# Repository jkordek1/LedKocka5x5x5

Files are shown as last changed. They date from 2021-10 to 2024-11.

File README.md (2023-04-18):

# LedKocka5x5x5


[]()



## What is it?
Just another 125 LED cube powered by ATmega16 microcontroller and HC595 shift registers.

## Video
Video of it in action: https://www.youtube.com/watch?v=YpSFf-s8Nvs

## Problems
Project BOM is not optimal. Due to electronic components shortage, "on-hand" available components were used.

## Images
 LED_Cube_5x5x5
<p align="center">
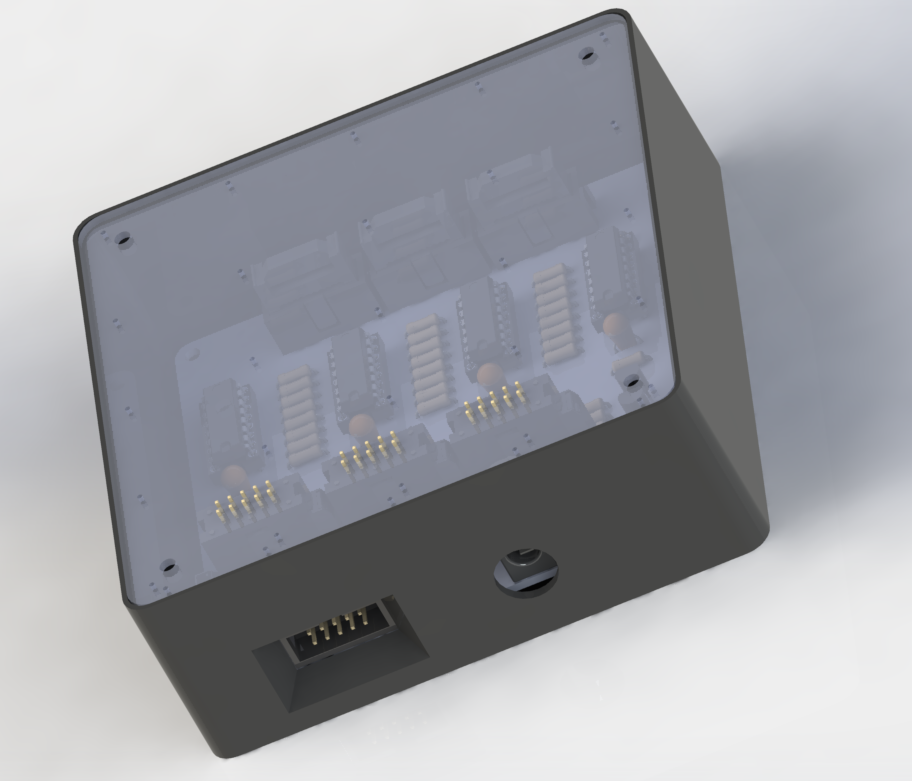
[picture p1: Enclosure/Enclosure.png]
 
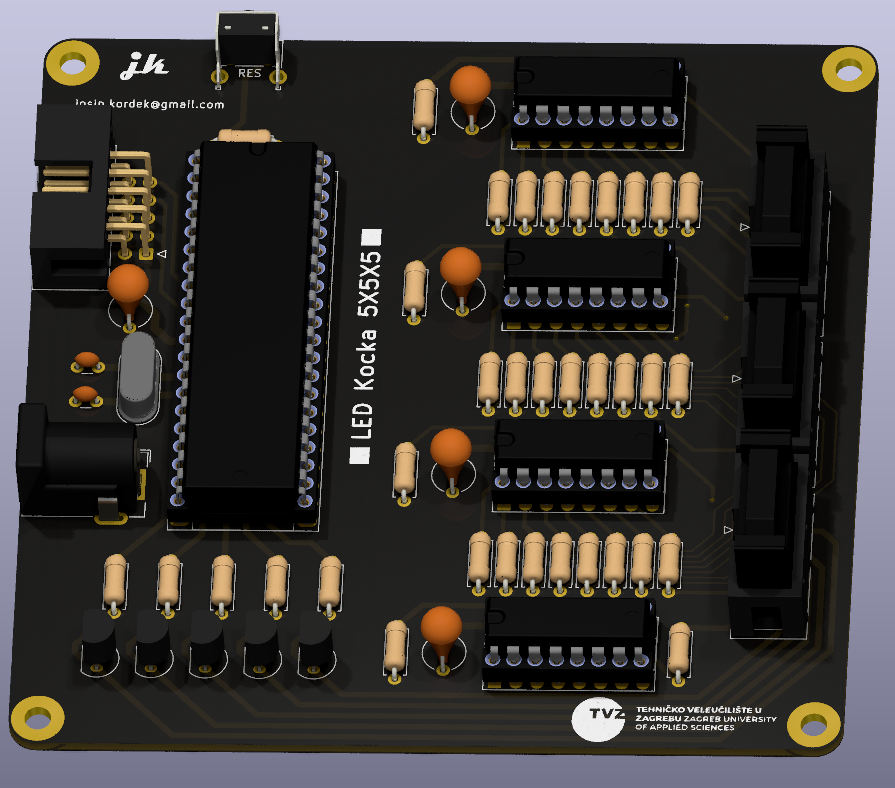
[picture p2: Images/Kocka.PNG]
 
</p>

## Project folder structure
    .
    ├── ...
    ├── Code                    # C code for microcontroller
    ├── Enclosure               # 3D files and images of enclosure
    ├── Images                  # Project images folder
    ├── Output files            # Gerber files folder
    ├── KiCad files             # Main folder
    │   ├── LED_Cube_5X5X5      # First KiCAD project folder
    │   └── LED_Cube_5X5X5_PCB2 # Second KiCAD project folder
    └── ...

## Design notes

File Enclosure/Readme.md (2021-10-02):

This directory contains Solidworks assembly and step models of PCBs



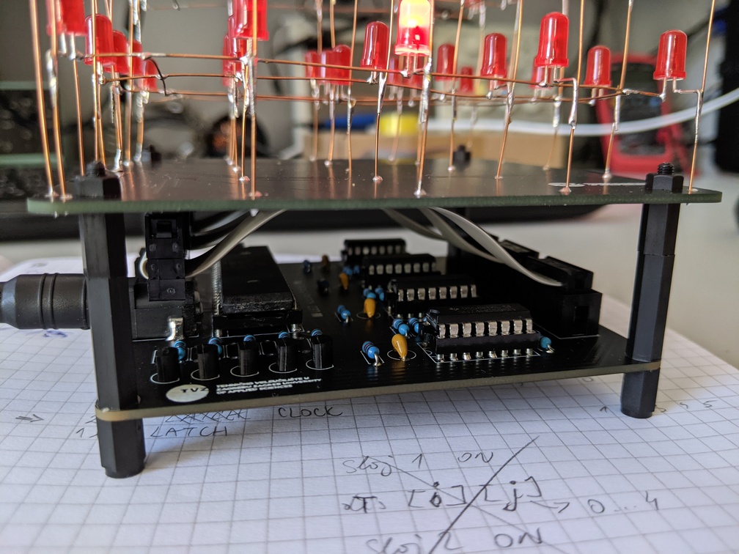
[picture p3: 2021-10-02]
Images/From inside.jpg

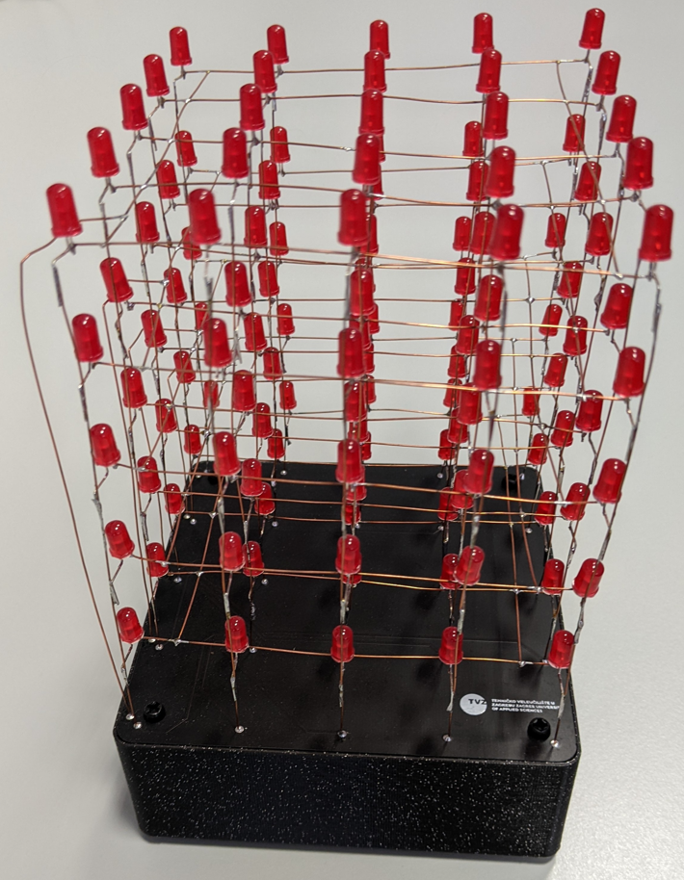
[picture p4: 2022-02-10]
Images/Finished.PNG

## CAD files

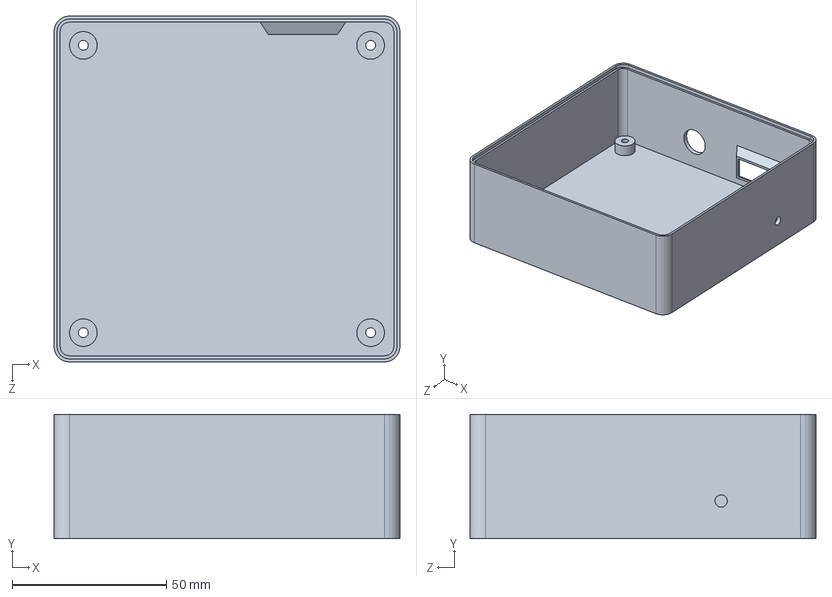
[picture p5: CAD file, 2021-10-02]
Enclosure/Enclosure_final.SLDPRT
112.0 x 40.2 x 112.0 mm

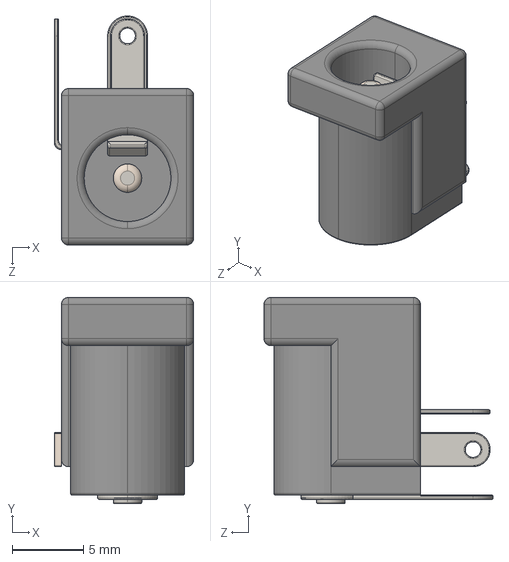
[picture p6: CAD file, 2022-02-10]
KiCad files/LED_Cube_5X5X5/3d modeli/K375A -PCM DC Power Jack 2mm Pin.STEP
9.80 x 14.5 x 16.1 mm

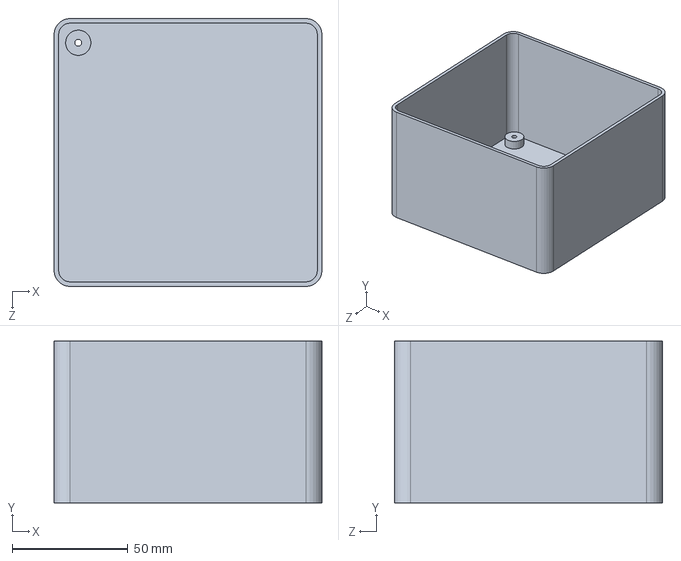
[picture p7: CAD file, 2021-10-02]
KiCad files/LED_Cube_5X5X5_PCB2/STEP/Kocka_kuciste.SLDPRT
116.0 x 70.0 x 116.0 mm

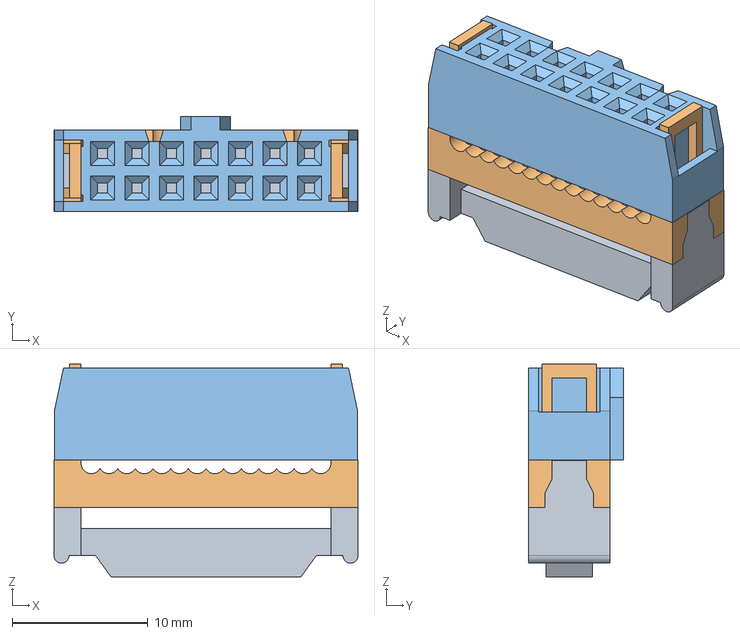
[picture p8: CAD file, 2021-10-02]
KiCad files/LED_Cube_5X5X5/3d modeli/2.54mm IDC Socket - Amphenol T812.stp
22.4 x 7.00 x 15.7 mm

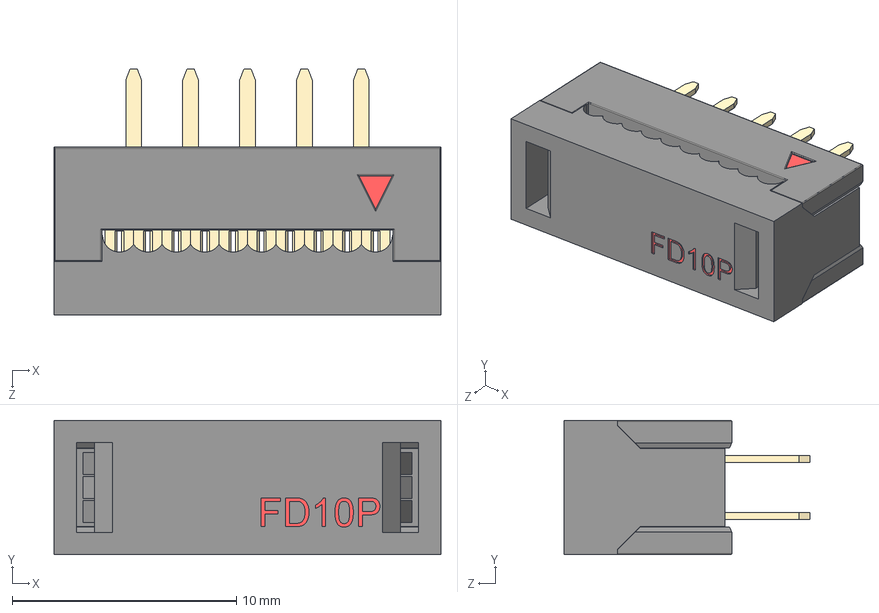
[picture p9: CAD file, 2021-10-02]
KiCad files/LED_Cube_5X5X5/3d modeli/FDC-10 ( DS1018-2.54-10 ).STEP
17.3 x 6.00 x 11.0 mm
FDC-10 ( DS1018-2-10S )
FDC-10 ( DS1018-2-10L )

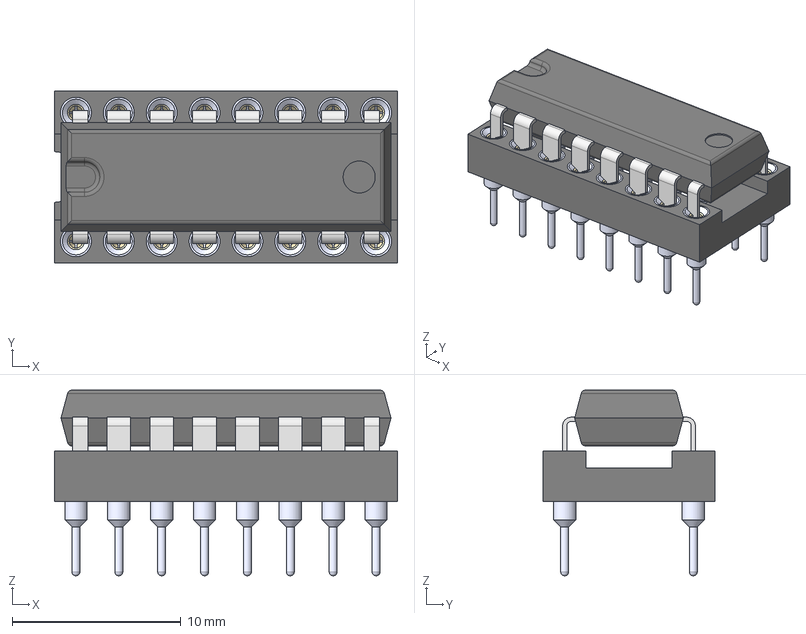
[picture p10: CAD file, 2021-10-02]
KiCad files/LED_Cube_5X5X5/3d modeli/DIP-16 on SCSM-16.step
20.3 x 10.2 x 11.0 mm
SCSM
DIP

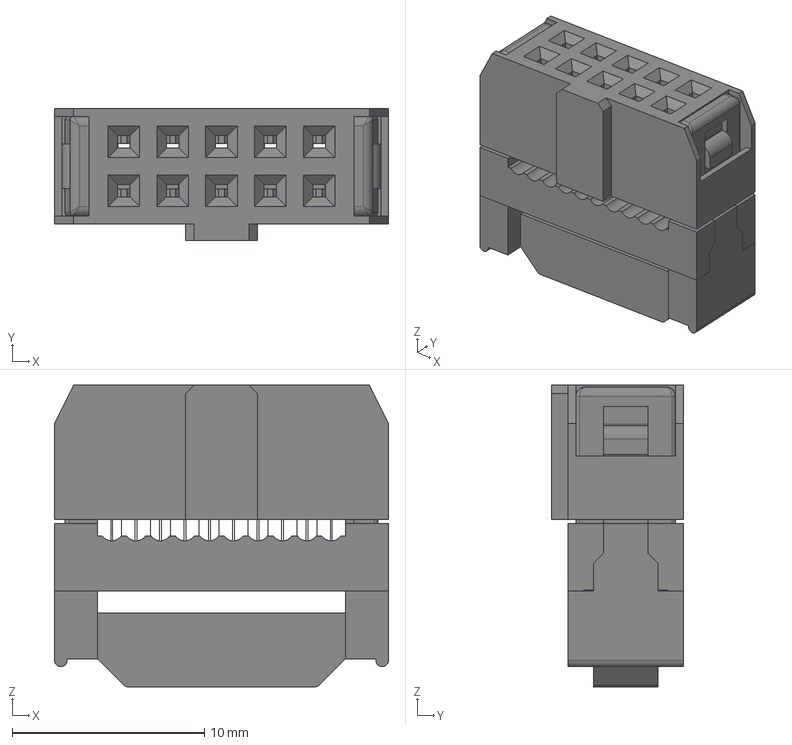
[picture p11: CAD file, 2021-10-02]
KiCad files/LED_Cube_5X5X5/3d modeli/61201023021 (rev1).stp
17.4 x 6.86 x 15.7 mm
Gehäuse
Kabelklemme
Verschluss
Pin x 10

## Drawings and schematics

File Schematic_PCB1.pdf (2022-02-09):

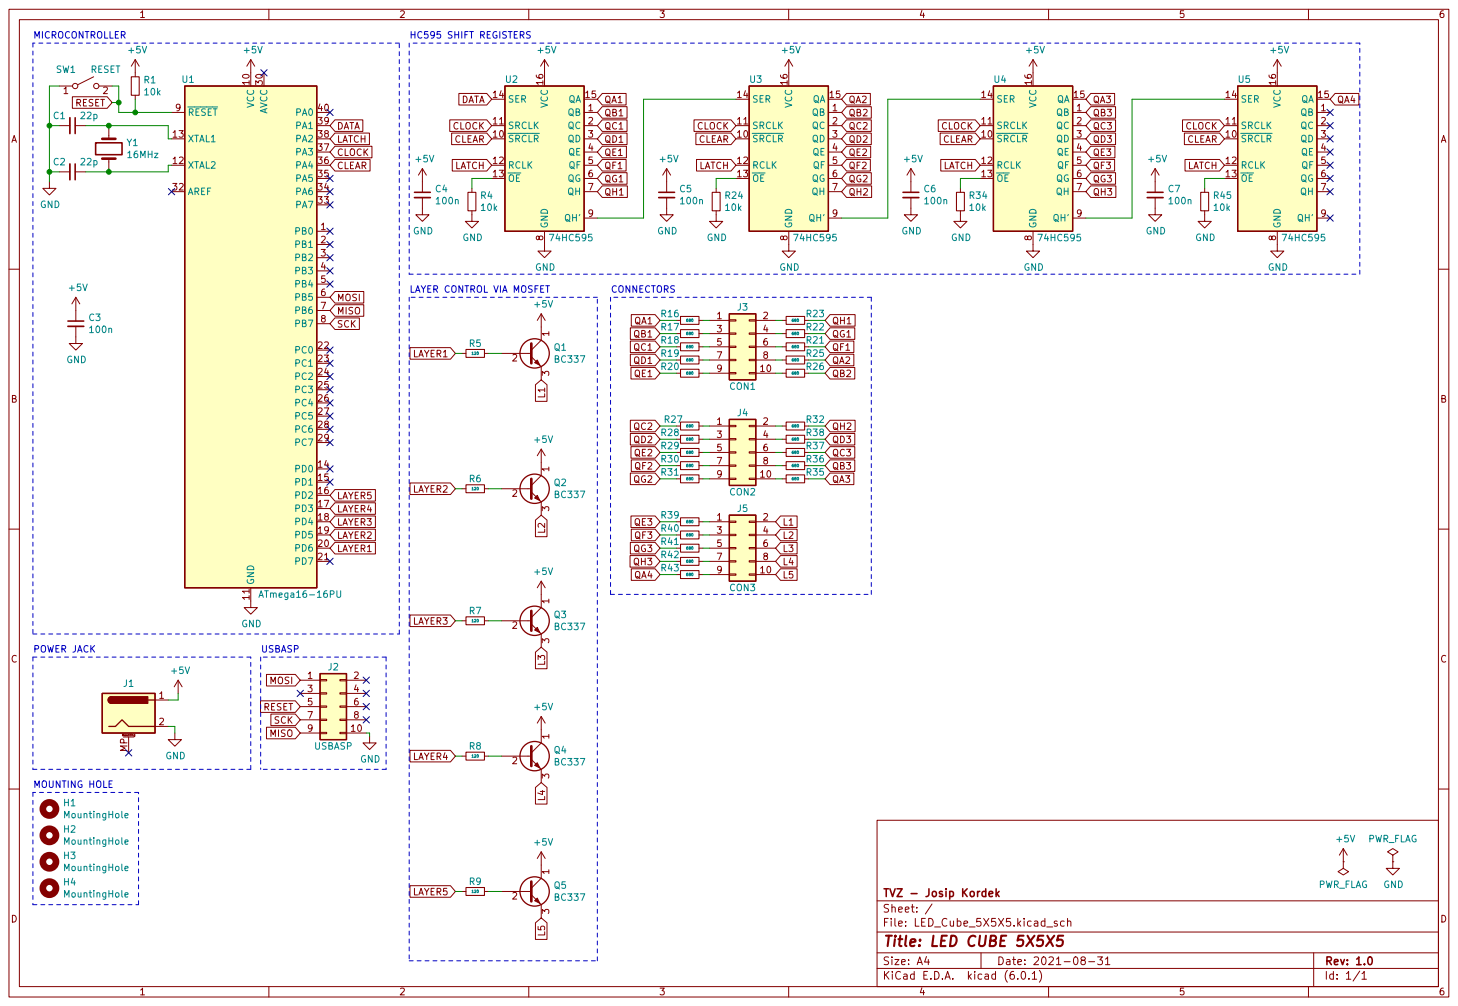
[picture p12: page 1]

3 Q3BC337 +5V QB 1 ~{SRCLR} 10 SRCLK 11 RCLK 12 ~{OE} 13 SER 14 QA 15 VCC 16 QC 2 QD 3 QE 4 QF 5 QG 6 QH 7 GND

File: LED_Cube_5X5X5.kicad_sch Sheet: / TVZ - Josip Kordek

Id: 1/1 Title: LED CUBE 5X5X5

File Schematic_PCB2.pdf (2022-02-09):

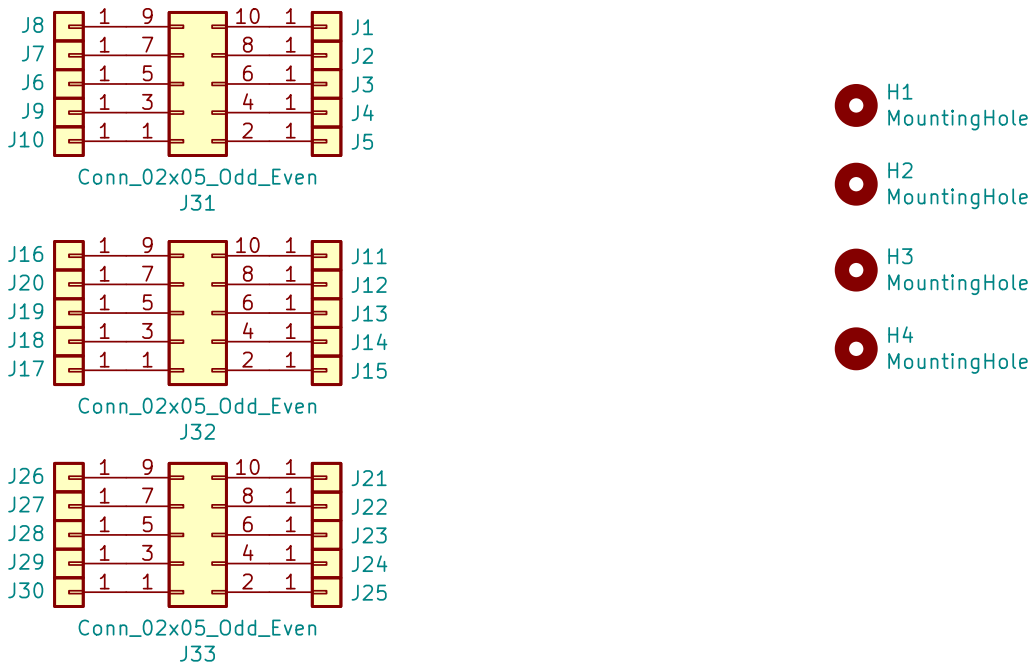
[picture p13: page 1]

Id: 1/1 Title: Upper plate

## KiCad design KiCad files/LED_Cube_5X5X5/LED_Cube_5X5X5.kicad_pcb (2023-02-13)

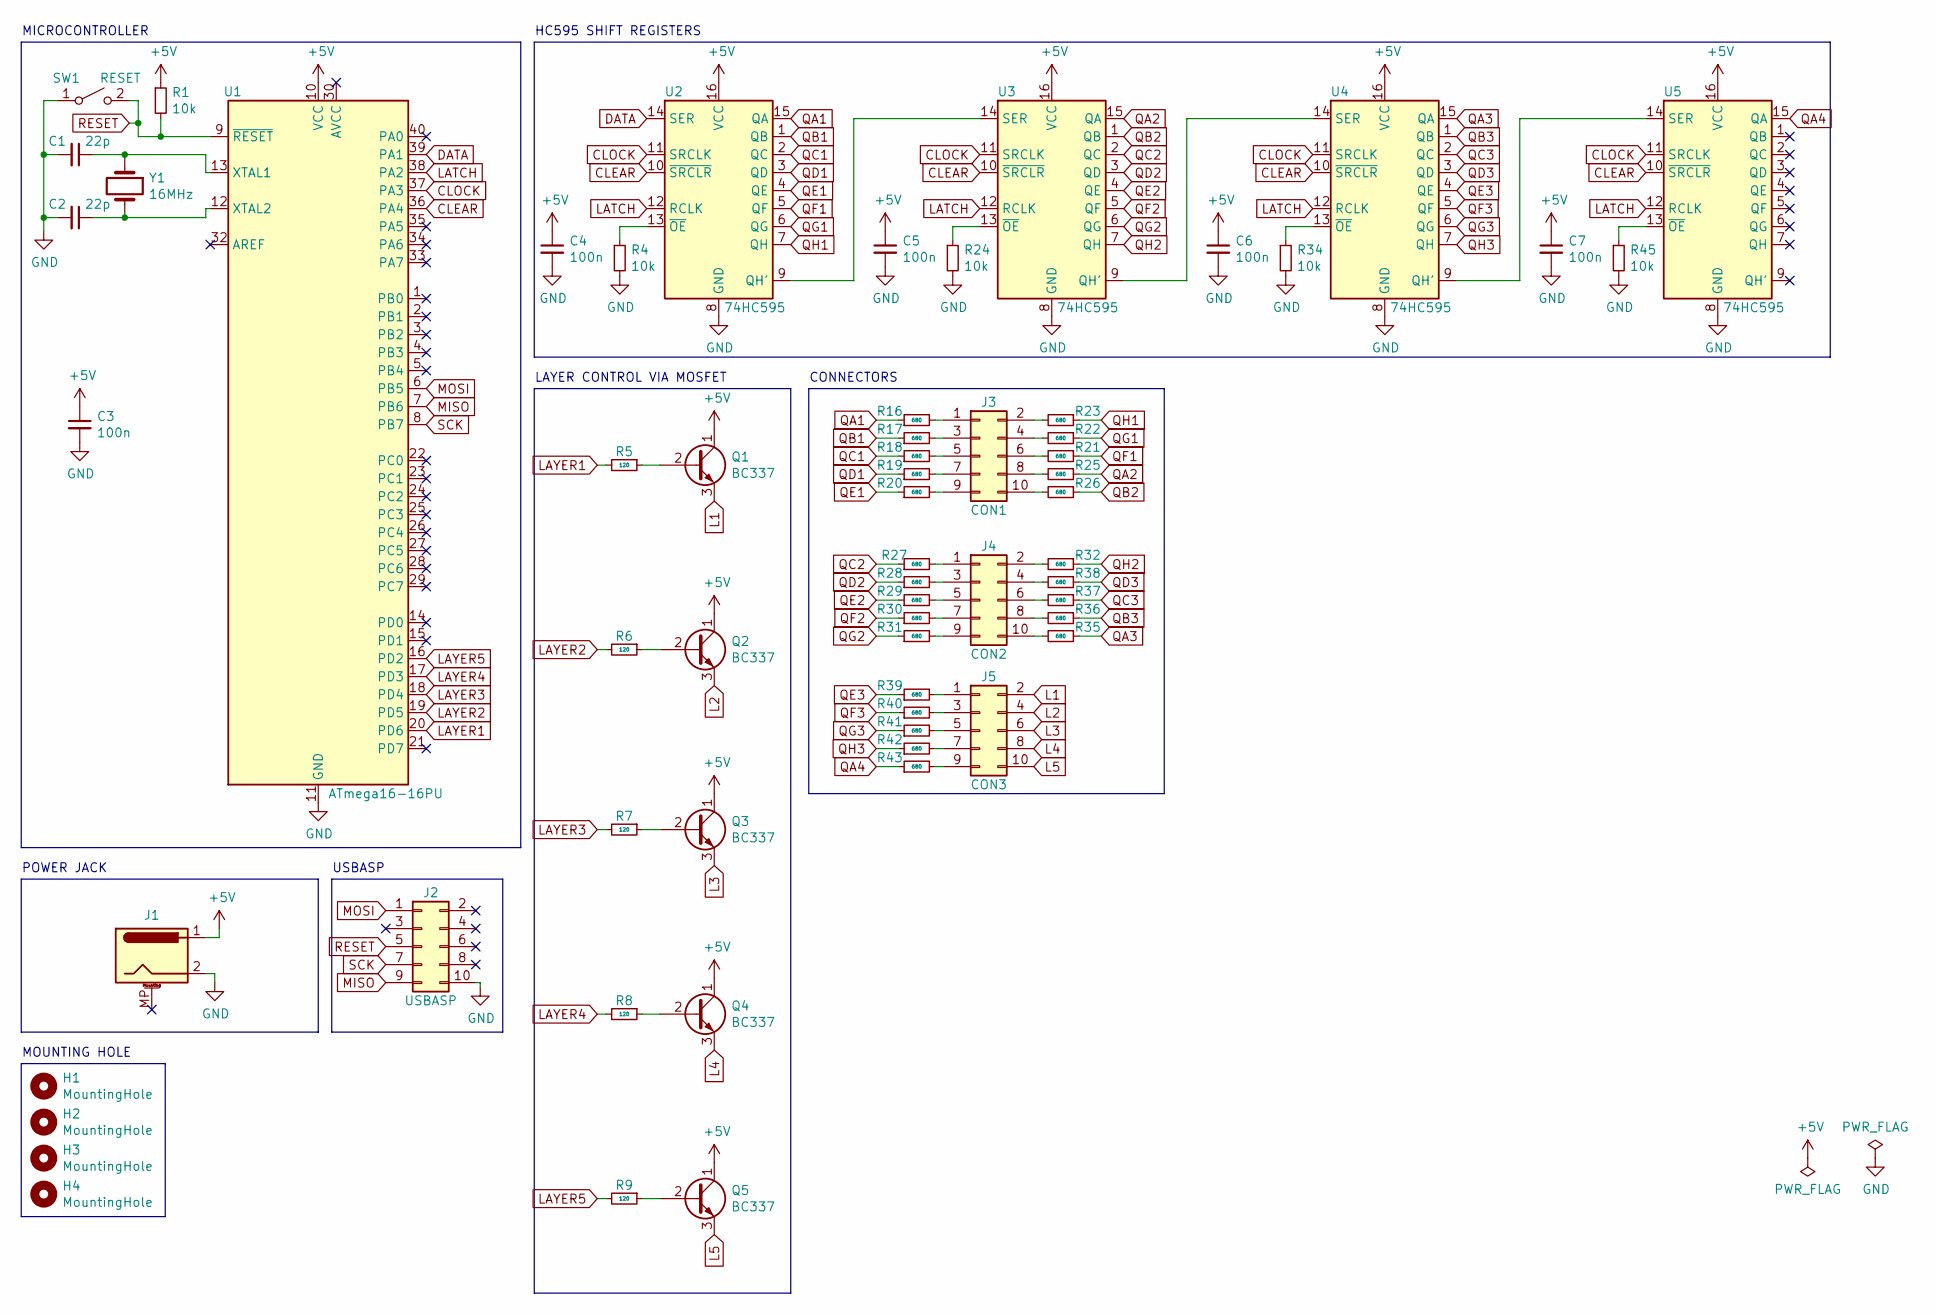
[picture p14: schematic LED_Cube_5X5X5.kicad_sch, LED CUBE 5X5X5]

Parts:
C1, C2: 22p; C_Disc_D3.0mm_W1.6mm_P2.50mm
C3, C4, C5, C6, C7: 100n; CP_Radial_Tantal_D5.0mm_P5.00mm
H1, H2, H3, H4: MountingHole; MountingHole_3.2mm_M3_Pad
J1: Barrel_Jack_MountingPin; BarrelJack_Wuerth_6941xx301002
J2: USBASP; IDC-Header_2x05_P2.54mm_Horizontal
J3: CON1; IDC-Header_2x05_P2.54mm_Vertical
J4: CON2; IDC-Header_2x05_P2.54mm_Vertical
J5: CON3; IDC-Header_2x05_P2.54mm_Vertical
Q1, Q2, Q3, Q4, Q5: BC337; TO-92_Inline
R1, R4, R24, R34, R45: 10k; R_Axial_DIN0207_L6.3mm_D2.5mm_P7.62mm_Horizontal
R5, R6, R7, R8, R9: 120; R_Axial_DIN0207_L6.3mm_D2.5mm_P7.62mm_Horizontal
R16, R17, R18, R19, R20, R21, R22, R23, R25, R26, R27, R28, R29, R30, R31, R32, R35, R36, R37, R38, R39, R40, R41, R42, R43: 680; R_Axial_DIN0207_L6.3mm_D2.5mm_P7.62mm_Horizontal
SW1: RESET; SW_Tactile_SPST_Angled_PTS645Vx39-2LFS
U1: ATmega16-16PU; DIP-40_W15.24mm_Socket_LongPads
U2, U3, U4, U5: 74HC595; DIP-16_W7.62mm_Socket_LongPads
Y1: 16MHz; Crystal_HC49-4H_Vertical

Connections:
+5V: C3.1, C4.1, C5.1, C6.1, C7.1, J1.1, Q1.1 (C), Q2.1 (C), Q3.1 (C), Q4.1 (C), Q5.1 (C), R1.1, U1.10 (VCC), U2.16 (VCC), U3.16 (VCC), U4.16 (VCC), U5.16 (VCC)
CLEAR: U1.36 (PA4), U2.10 (~SRCLR), U3.10 (~SRCLR), U4.10 (~SRCLR), U5.10 (~SRCLR)
CLOCK: U1.37 (PA3), U2.11 (SRCLK), U3.11 (SRCLK), U4.11 (SRCLK), U5.11 (SRCLK)
DATA: U1.39 (PA1), U2.14 (SER)
GND: C1.2, C2.2, C3.2, C4.2, C5.2, C6.2, C7.2, J1.2, J2.10, R4.2, R24.2, R34.2, R45.2, SW1.1 (A), U1.11 (GND), U1.31 (GND), U2.8 (GND), U3.8 (GND), U4.8 (GND), U5.8 (GND)
L1: J5.2, Q1.3 (E)
L2: J5.4, Q2.3 (E)
L3: J5.6, Q3.3 (E)
L4: J5.8, Q4.3 (E)
L5: J5.10, Q5.3 (E)
LATCH: U1.38 (PA2), U2.12 (RCLK), U3.12 (RCLK), U4.12 (RCLK), U5.12 (RCLK)
LAYER1: R5.2, U1.20 (PD6)
LAYER2: R6.2, U1.19 (PD5)
LAYER3: R7.2, U1.18 (PD4)
LAYER4: R8.2, U1.17 (PD3)
LAYER5: R9.2, U1.16 (PD2)
MISO: J2.9, U1.7 (PB6)
MOSI: J2.1, U1.6 (PB5)
unnamed: C1.1, U1.13 (XTAL1), Y1.1
unnamed: C2.1, U1.12 (XTAL2), Y1.2
unnamed: J3.1, R16.2
unnamed: J3.2, R23.2
unnamed: J3.3, R17.2
unnamed: J3.4, R22.2
unnamed: J3.5, R18.2
unnamed: J3.6, R21.2
unnamed: J3.7, R19.2
unnamed: J3.8, R25.2
unnamed: J3.9, R20.2
unnamed: J3.10, R26.2
unnamed: J4.1, R27.2
unnamed: J4.2, R32.2
unnamed: J4.3, R28.2
unnamed: J4.4, R38.2
unnamed: J4.5, R29.2
unnamed: J4.6, R37.2
unnamed: J4.7, R30.2
unnamed: J4.8, R36.2
unnamed: J4.9, R31.2
unnamed: J4.10, R35.2
unnamed: J5.1, R39.2
unnamed: J5.3, R40.2
unnamed: J5.5, R41.2
unnamed: J5.7, R42.2
unnamed: J5.9, R43.2
unnamed: Q1.2 (B), R5.1
unnamed: Q2.2 (B), R6.1
unnamed: Q3.2 (B), R7.1
unnamed: Q4.2 (B), R8.1
unnamed: Q5.2 (B), R9.1
unnamed: R4.1, U2.13 (~OE)
unnamed: R24.1, U3.13 (~OE)
unnamed: R34.1, U4.13 (~OE)
unnamed: R45.1, U5.13 (~OE)
unnamed: U2.9 (QH'), U3.14 (SER)
unnamed: U3.9 (QH'), U4.14 (SER)
unnamed: U4.9 (QH'), U5.14 (SER)
QA1: R16.1, U2.15 (QA)
QA2: R25.1, U3.15 (QA)
QA3: R35.1, U4.15 (QA)
QA4: R43.1, U5.15 (QA)
QB1: R17.1, U2.1 (QB)
QB2: R26.1, U3.1 (QB)
QB3: R36.1, U4.1 (QB)
QC1: R18.1, U2.2 (QC)
QC2: R27.1, U3.2 (QC)
QC3: R37.1, U4.2 (QC)
QD1: R19.1, U2.3 (QD)
QD2: R28.1, U3.3 (QD)
QD3: R38.1, U4.3 (QD)
QE1: R20.1, U2.4 (QE)
QE2: R29.1, U3.4 (QE)
QE3: R39.1, U4.4 (QE)
QF1: R21.1, U2.5 (QF)
QF2: R30.1, U3.5 (QF)
QF3: R40.1, U4.5 (QF)
QG1: R22.1, U2.6 (QG)
QG2: R31.1, U3.6 (QG)
QG3: R41.1, U4.6 (QG)
QH1: R23.1, U2.7 (QH)
QH2: R32.1, U3.7 (QH)
QH3: R42.1, U4.7 (QH)
RESET: J2.5, R1.2, SW1.2 (B), U1.9 (~RESET)
SCK: J2.7, U1.8 (PB7)

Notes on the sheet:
POWER JACK
USBASP
HC595 SHIFT REGISTERS
LAYER CONTROL VIA MOSFET
MOUNTING HOLE
MICROCONTROLLER
CONNECTORS

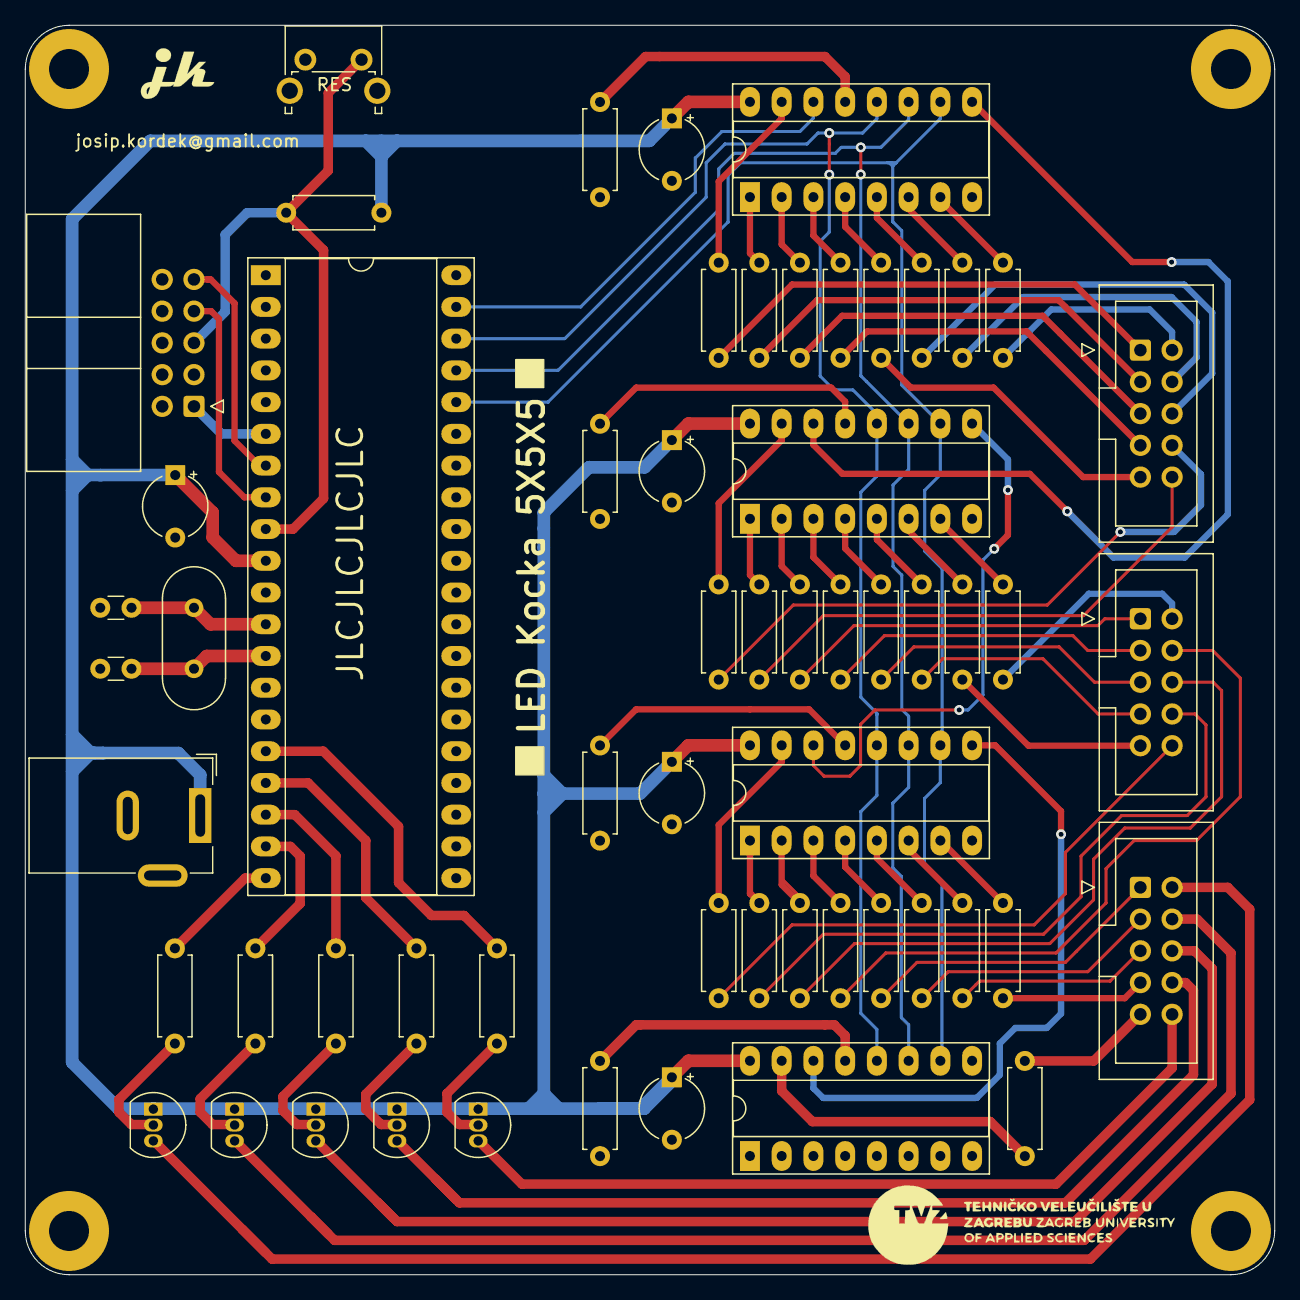
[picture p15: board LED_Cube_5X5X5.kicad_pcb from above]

Board: 2 copper layers, 100.0 x 100.0 mm, 63 parts (0 on the bottom side), 84 nets.

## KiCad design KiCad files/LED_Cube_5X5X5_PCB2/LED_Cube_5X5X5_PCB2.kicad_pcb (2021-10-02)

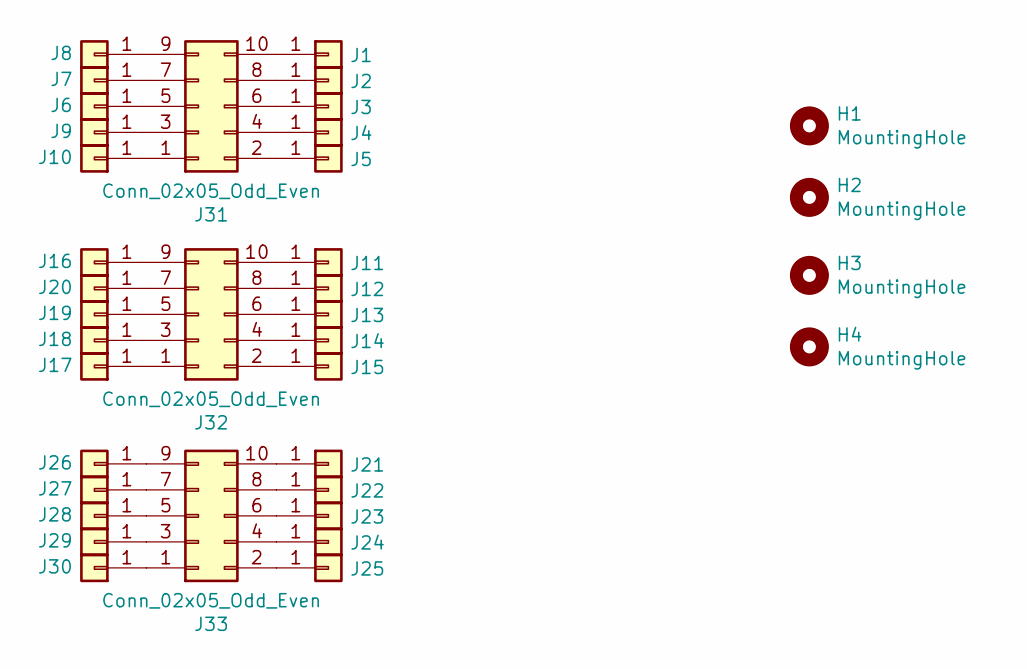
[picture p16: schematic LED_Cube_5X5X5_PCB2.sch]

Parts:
H1, H2, H3, H4: MountingHole; MountingHole_3.2mm_M3
J1, J2, J3, J4, J5, J6, J7, J8, J9, J10, J11, J12, J13, J14, J15, J16, J17, J18, J19, J20, J21, J22, J23, J24, J25, J26, J27, J28, J29, J30: Conn_01x01; Pin_D1.0mm_L10.0mm
J31, J32, J33: Conn_02x05_Odd_Even; PinHeader_2x05_P2.54mm_Vertical_SMD

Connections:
unnamed: J1.1, J31.10
unnamed: J2.1, J31.8
unnamed: J3.1, J31.6
unnamed: J10.1, J31.1
unnamed: J11.1, J32.10
unnamed: J12.1, J32.8
unnamed: J13.1, J32.6
unnamed: J14.1, J32.4
unnamed: J15.1, J32.2
unnamed: J16.1, J32.9
unnamed: J17.1, J32.1
unnamed: J18.1, J32.3
unnamed: J19.1, J32.5
unnamed: J20.1, J32.7
unnamed: J21.1, J33.10
unnamed: J22.1, J33.8
unnamed: J23.1, J33.6
unnamed: J24.1, J33.4
unnamed: J25.1, J33.2
unnamed: J26.1, J33.9
unnamed: J27.1, J33.7
unnamed: J28.1, J33.5
unnamed: J29.1, J33.3
unnamed: J30.1, J33.1
unnamed: J5.1, J31.2
unnamed: J9.1, J31.3
unnamed: J4.1, J31.4
unnamed: J6.1, J31.5
unnamed: J7.1, J31.7
unnamed: J8.1, J31.9

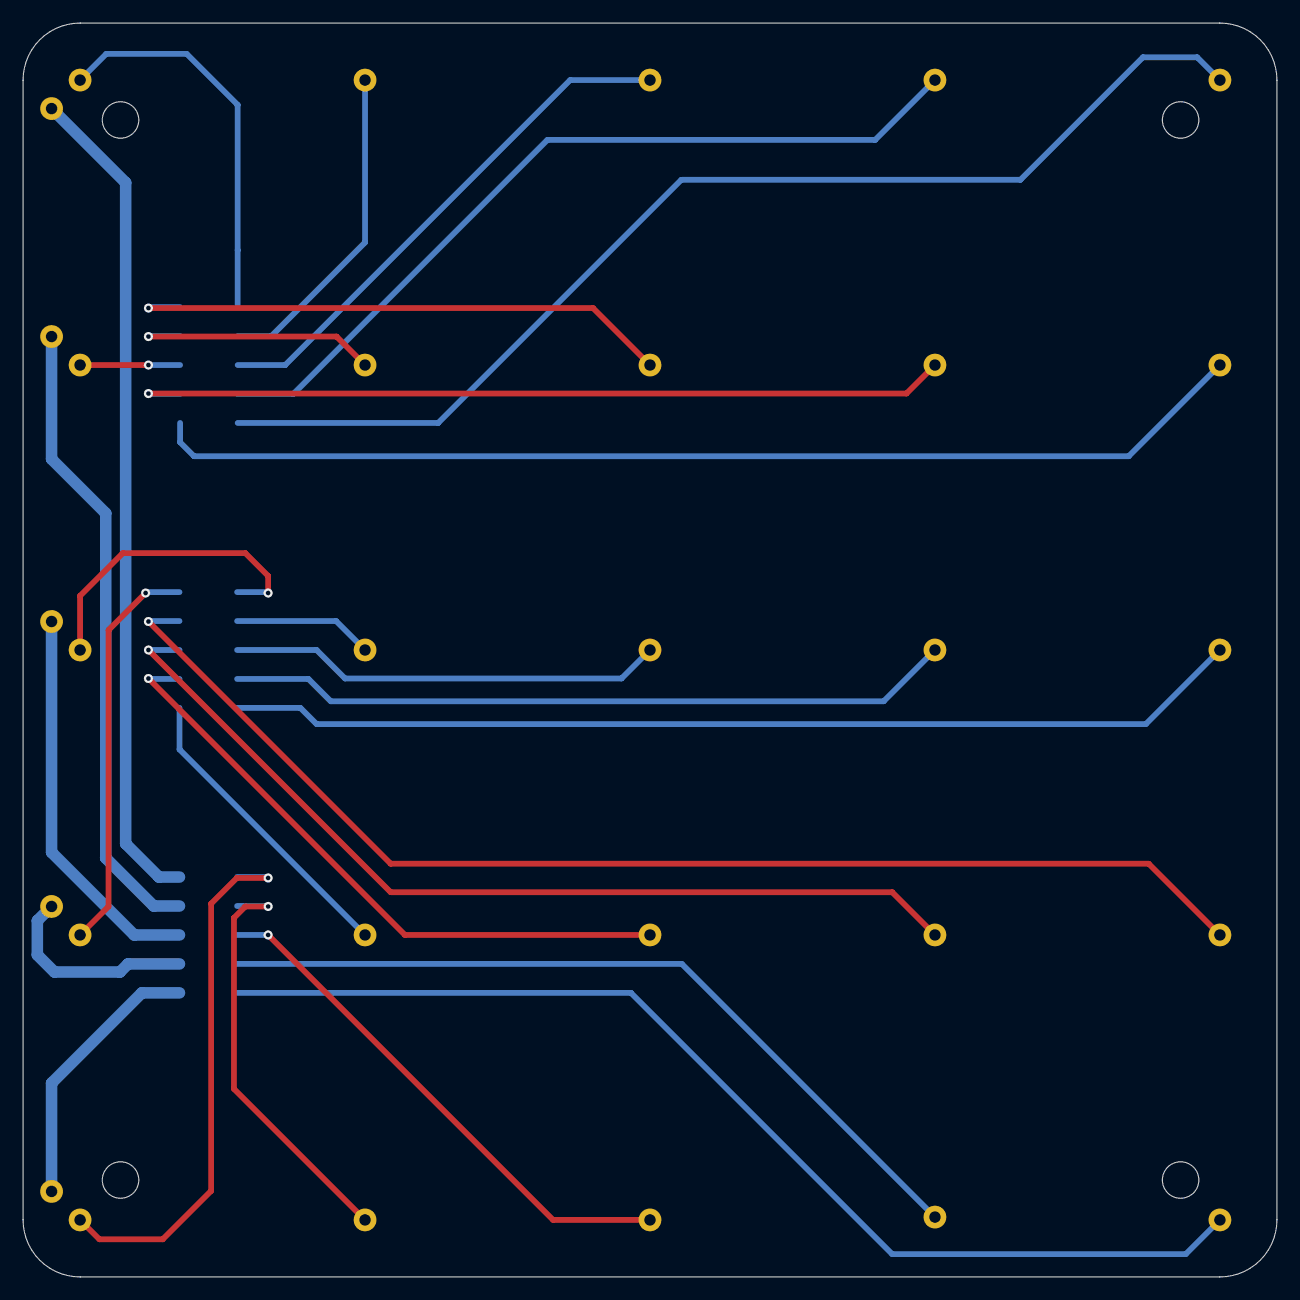
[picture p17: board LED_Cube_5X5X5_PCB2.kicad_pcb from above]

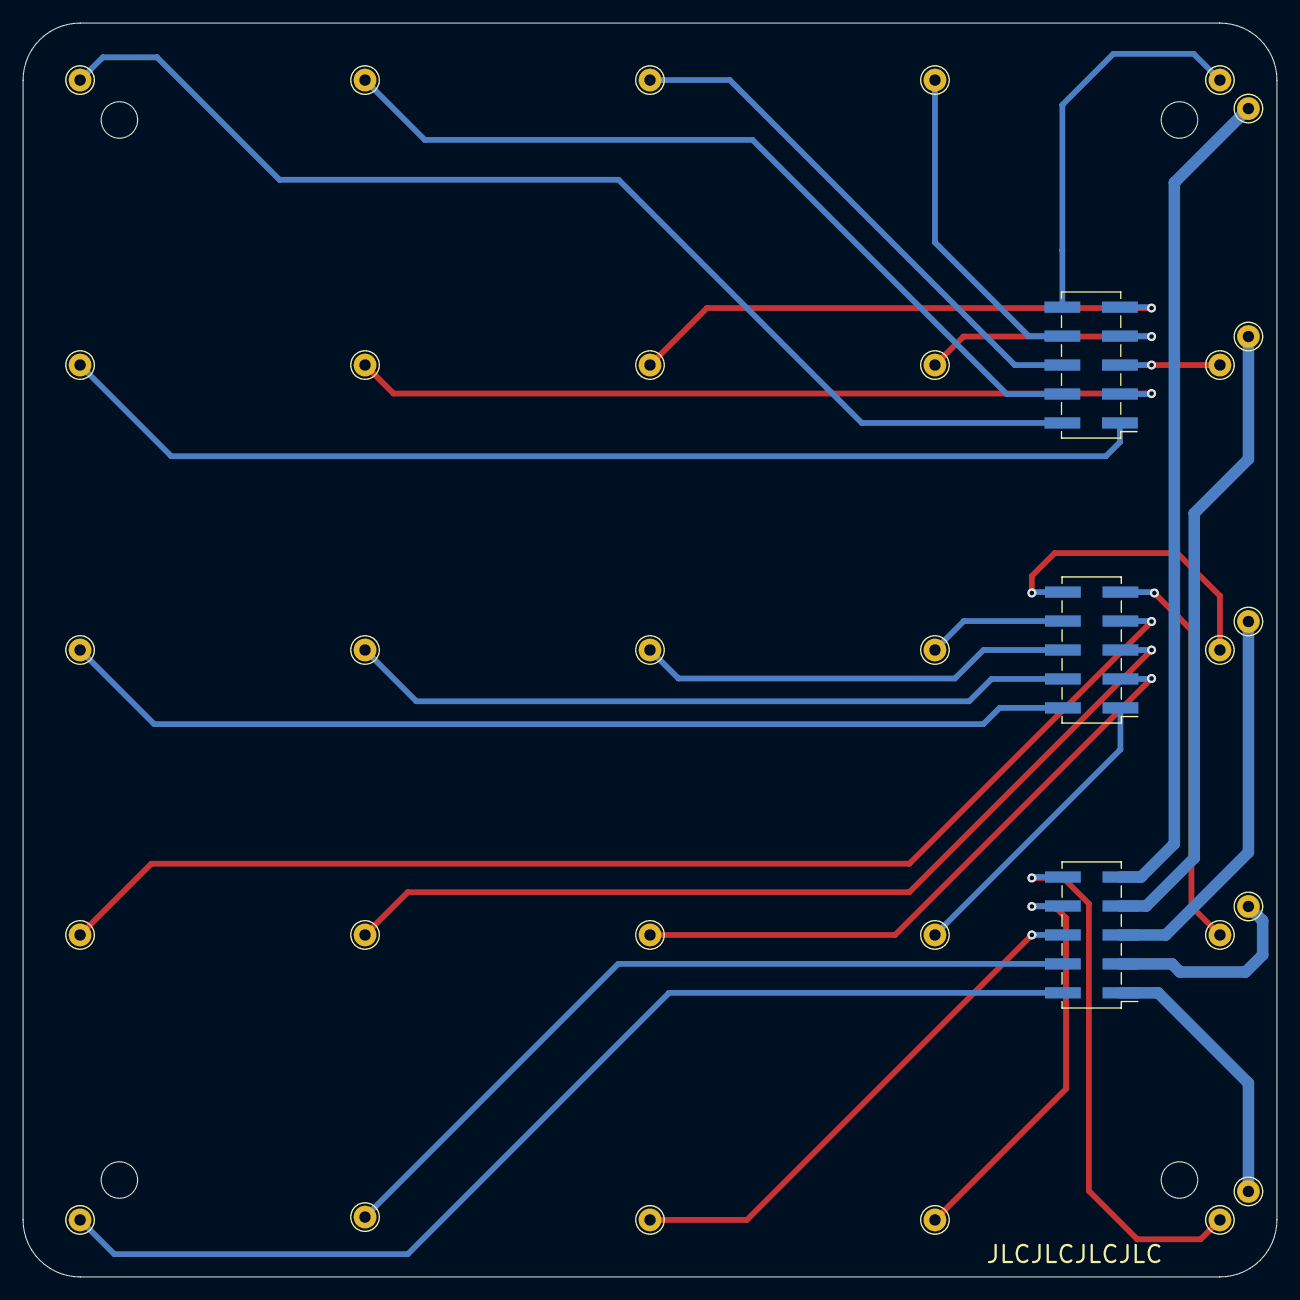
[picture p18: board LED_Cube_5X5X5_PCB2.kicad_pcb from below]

Board: 2 copper layers, 110.0 x 110.0 mm, 37 parts (33 on the bottom side), 30 nets.

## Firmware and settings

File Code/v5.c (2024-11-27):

#ifdef F_CPU
#undef F_CPU
#define F_CPU 16000000l
#endif

#include "AVR lib/AVR_lib.h"
#include <avr/io.h>
#include <util/delay.h>
#include <avr/interrupt.h>
#include <stdbool.h>
#include <stdio.h>

uint8_t trenutni_sloj = 1;
uint8_t trenutni_stupac = 6;
uint8_t slovo = 1;

uint8_t prazan_hod = 0;
bool smjer = true;
uint8_t MOD = 1;
uint8_t MOD2BROJAC = 1;
uint8_t cntr = 0;
uint8_t cntr2 = 0;
uint8_t var = 0;

#define DATA PA1
#define CLOCK PA3
#define LATCH PA2
#define CLEAR PA4

#define LAYER1 PD2
#define LAYER2 PD3
#define LAYER3 PD4
#define LAYER4 PD5
#define LAYER5 PD6

int T[5][5] = {
	{0, 0, 0, 0, 0},
	{1, 1, 0, 1, 1},
	{1, 1, 0, 1, 1},
	{1, 1, 0, 1, 1},
	{1, 1, 0, 1, 1}
};

int V[5][5] = {
	{0, 1, 1, 1, 0},
	{0, 1, 1, 1, 0},
	{1, 0, 1, 0, 1},
	{1, 0, 1, 0, 1},
	{1, 1, 0, 1, 1}
};

int Z[5][5] = {
	{0, 0, 0, 0, 0},
	{1, 0, 1, 1, 1},
	{1, 1, 0, 1, 1},
	{1, 1, 1, 0, 1},
	{0, 0, 0, 0, 0}
};

int K[5][5] = {
	{0, 1, 1, 1, 0},
	{1, 0, 1, 1, 0},
	{1, 1, 0, 0, 0},
	{1, 0, 1, 1, 0},
	{0, 1, 1, 1, 0}
};

int I[5][5] = {
	{1, 1, 0, 1, 1},
	{1, 1, 1, 1, 1},
	{1, 1, 0, 1, 1},
	{1, 1, 0, 1, 1},
	{1, 1, 0, 1, 1}
};

int R[5][5] = {
	{1, 1, 0, 0, 0},
	{1, 0, 1, 1, 0},
	{1, 1, 0, 0, 0},
	{1, 1, 0, 1, 0},
	{1, 0, 1, 1, 0}
};

int E[5][5] = {
	{0, 0, 0, 0, 0},
	{1, 1, 1, 1, 0},
	{1, 0, 0, 0, 0},
	{1, 1, 1, 1, 0},
	{0, 0, 0, 0, 0}
};

int L[5][5] = {
	{1, 1, 1, 1, 0},
	{1, 1, 1, 1, 0},
	{1, 1, 1, 1, 0},
	{1, 1, 1, 1, 0},
	{0, 0, 0, 0, 0}
};

int O[5][5] = {
	{1, 0, 0, 0, 1},
	{0, 1, 1, 1, 0},
	{0, 1, 1, 1, 0},
	{0, 1, 1, 1, 0},
	{1, 0, 0, 0, 1}
};

int prazno[5][5] = {
	{1, 1, 1, 1, 1},
	{1, 1, 1, 1, 1},
	{1, 1, 1, 1, 1},
	{1, 1, 1, 1, 1},
	{1, 1, 1, 1, 1}
};

int A1[5][5] = {
	{1, 1, 1, 1, 1},
	{1, 1, 1, 1, 1},
	{1, 1, 0, 1, 1},
	{1, 1, 1, 1, 1},
	{1, 1, 1, 1, 1}
};

int A2[5][5] = {
	{1, 1, 1, 1, 1},
	{1, 0, 0, 0, 1},
	{1, 0, 1, 0, 1},
	{1, 0, 0, 0, 1},
	{1, 1, 1, 1, 1}
};

int A3[5][5] = {
	{0, 0, 0, 0, 0},
	{0, 1, 1, 1, 0},
	{0, 1, 1, 1, 0},
	{0, 1, 1, 1, 0},
	{0, 0, 0, 0, 0}
};

int M[125]= {0, 0, 0, 0, 0, 0, 1, 1, 1, 0, 0, 1, 1, 1, 0, 0, 1, 1, 1, 0, 0, 0, 0, 0, 0, 1, 1, 1, 1, 1, 1, 0, 0, 0, 1, 1, 0, 0, 0, 1, 1, 0, 0, 0, 1, 0, 0, 1, 0, 1,
	1, 0, 0, 1, 0, 0, 1, 1, 0, 1, 1, 0, 0, 1, 0, 0, 1, 0, 1, 0, 1, 0, 0, 0, 1, 1, 1, 1, 0, 0, 1, 1, 0, 1, 0, 1, 0, 1, 1, 0, 1, 1, 0, 1, 0, 0, 0, 0, 0, 1,
0, 1, 0, 0, 0, 1, 0, 1, 0, 1, 0, 0, 1, 0, 0, 1, 1, 1, 0, 0, 0, 0, 0, 1, 1};

void all_off(){
	for(int j = 0; j < 25; j++){
		set_port(PORTA, DATA, 1);
		TOGGLE_PORT(PORTA, CLOCK); //1
		TOGGLE_PORT(PORTA, CLOCK); //0
	}

	TOGGLE_PORT(PORTA, LATCH); //1
	TOGGLE_PORT(PORTA, LATCH); //0
	
}

void all_on(){
	for(int j = 0; j < 25; j++){
		set_port(PORTA, DATA, 0);
		TOGGLE_PORT(PORTA, CLOCK); //1
		TOGGLE_PORT(PORTA, CLOCK); //0
	}

	TOGGLE_PORT(PORTA, LATCH); //1
	TOGGLE_PORT(PORTA, LATCH); //0
	
}

void sloj(int x){
	
	switch(x){
		
		case 1:
		set_port(PORTD, LAYER1, 1);
		set_port(PORTD, LAYER2, 0);
		set_port(PORTD, LAYER5, 0);
		break;
		
		case 2:
		set_port(PORTD, LAYER2, 1);
		set_port(PORTD, LAYER1, 0);
		set_port(PORTD, LAYER3, 0);
		break;
		
		case 3:
		set_port(PORTD, LAYER3, 1);
		set_port(PORTD, LAYER2, 0);
		set_port(PORTD, LAYER4, 0);
		break;
		
		case 4:
		set_port(PORTD, LAYER4, 1);
		set_port(PORTD, LAYER3, 0);
		set_port(PORTD, LAYER5, 0);
		break;
		
		case 5:
		set_port(PORTD, LAYER5, 1);
		set_port(PORTD, LAYER1, 0);
		set_port(PORTD, LAYER4, 0);
		break;
		
	}
}

ISR(TIMER0_OVF_vect){ // prekidna rutina za timer0
	
	if (MOD == 1){
		TCNT0 = 200; // pocetna vrijednost registra
		sloj(trenutni_sloj);
		
		for(int j = 0; j < (trenutni_stupac-1)*5; j++){
			set_port(PORTA, DATA, 1);
			TOGGLE_PORT(PORTA, CLOCK); //1
			TOGGLE_PORT(PORTA, CLOCK); //0
		}
		
		for(int i = 0; i < 5; i++){
			if(slovo == 1){
				set_port(PORTA, DATA, T[trenutni_sloj - 1][i]);
			}
			else if(slovo == 2){
				set_port(PORTA, DATA, V[trenutni_sloj - 1][i]);
			}
			else if(slovo == 3){
				set_port(PORTA, DATA, Z[trenutni_sloj - 1][i]);
			}
			else if(slovo == 4){
				set_port(PORTA, DATA, prazno[trenutni_sloj - 1][i]);
			}
			else if(slovo == 5){
				set_port(PORTA, DATA, E[trenutni_sloj - 1][i]);
			}
			else if(slovo == 6){
				set_port(PORTA, DATA, L[trenutni_sloj - 1][i]);
			}
			else if(slovo == 7){
				set_port(PORTA, DATA, O[trenutni_sloj - 1][i]);
			}
			else if(slovo == 9){
				set_port(PORTA, DATA, prazno[trenutni_sloj - 1][i]);
			}
			TOGGLE_PORT(PORTA, CLOCK); //1
			TOGGLE_PORT(PORTA, CLOCK); //0
		}
		for(int j = 0; j < 25 - trenutni_stupac*5; j++){
			set_port(PORTA, DATA, 1);
			TOGGLE_PORT(PORTA, CLOCK); //1
			TOGGLE_PORT(PORTA, CLOCK); //0
		}
		
		TOGGLE_PORT(PORTA, LATCH); //1
		TOGGLE_PORT(PORTA, LATCH); //0
		trenutni_sloj++;

		if(trenutni_sloj == 6)	trenutni_sloj = 1;
	}
	else if (MOD == 3){
		TCNT0 = 53;
		prazan_hod++;
		if(prazan_hod == 12){
			var++;
			if (var == 5) var = 0;
			prazan_hod = 0;
			cntr2++;
			if (cntr2 == 60){
				cntr2 = 0;
				MOD = 1;
			}
		}
		
	}
}

void inicijalizacija(){
	
	TCCR0 |= (0 << WGM01 ) | (0 << WGM00 ) ; // normalan na?in rada
	TCCR0 |= (1 << CS02 ) | (0 << CS01 ) | (1 << CS00 ) ; // F_CPU / 1024
	TIMSK |= (1 << TOIE0 ) ; // omoguæi prekid TOV0
	
	TCCR2 |= (0 << WGM20 ) | (0 << WGM21 ) ;
	TCCR2 |= (1 << CS22 ) | (1 << CS21 ) | (1 << CS20 ) ; // F_CPU / 1024
	TIMSK |= (1 << TOIE2 ) ; // omoguæi prekid TOV0

	//DATA, CLOCK i LATCH pinovi postavljeni kao izlazni
	DDRA |= (1 << DATA) | (1 << CLOCK) | (1 << LATCH);
	
	//pinovi slojeva postavljeni kao izlazni
	DDRD |= (1 << LAYER1) | (1 << LAYER2) | (1 << LAYER3) | (1 << LAYER4) | (1 << LAYER5);
	
	//DATA 0
	set_port(PORTA, DATA, 0);

	DDRA |= (1 << CLEAR);
	PORTA |= (1 << CLEAR);
	
	TCNT0 = 200;
	TCNT2 = 26;
	
	all_off();
	
	sei();
}

ISR ( TIMER2_OVF_vect ) { // prekidna rutina za timer2
	if(MOD == 1){
		TCNT2 = 26; // po? etna vrijednost registra
		prazan_hod ++;
		if ( prazan_hod == 6){
			trenutni_stupac--;
			if (trenutni_stupac == 0) {
				slovo++;
				if (slovo == 10) {
					slovo = 1;
					trenutni_sloj = 1;
					MOD = 2;
					all_on();
					set_port(PORTD, PD4, 0);
					prazan_hod = 0;
				}
				trenutni_stupac = 5;
			}
			prazan_hod = 0;
		}
	}
	else if (MOD == 2){
		TCNT2 = 53;
		prazan_hod ++;
		if ( prazan_hod == 12){
			sloj(trenutni_sloj);
			if (smjer) trenutni_sloj++;
			else trenutni_sloj--;
			if(trenutni_sloj == 5 || trenutni_sloj == 1){
				MOD2BROJAC++;
				smjer = !smjer;
			}
			if(MOD2BROJAC == 13) {
				MOD = 3;
				trenutni_sloj = 1;
				MOD2BROJAC = 1;
				smjer = true;
			}
			prazan_hod = 0;
		}
		
	}
	else if ( MOD == 3){
		TCNT2 = 200; // po? etna vrijednost registra
		sloj(cntr + 1);
		for(int i = 0; i < 25; i++){
			set_port(PORTA, DATA, M[i + 25 * cntr + var]);
			TOGGLE_PORT(PORTA, CLOCK); //1
			TOGGLE_PORT(PORTA, CLOCK); //0
		}
		TOGGLE_PORT(PORTA, LATCH); //1
		TOGGLE_PORT(PORTA, LATCH); //0
		cntr++;
		if (cntr == 5) cntr = 0;
		
	}
}

int main(void){
	
	inicijalizacija();
	
	while(1){
		
	}
	return 0;
}

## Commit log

2021-10-02 Initial release
    [2.54mm IDC Socket - Amphenol T812.stp, 61201023021 (rev1).stp, DIP-16 on SCSM-16.step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]
2021-10-02 Uređeno
    [Enclosure_final.SLDPRT]
2022-02-09 PCB image
2022-02-09 gerber and bom
    [LED_Cube_5X5X5-B_Cu.gbr, LED_Cube_5X5X5-B_Mask.gbr, LED_Cube_5X5X5-B_Paste.gbr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]
2022-02-10 3d model
    [K375A -PCM DC Power Jack 2mm Pin.STEP, LED_Cube_5X5X5.kicad_pcb, LED_Cube_5X5X5.kicad_sch]
